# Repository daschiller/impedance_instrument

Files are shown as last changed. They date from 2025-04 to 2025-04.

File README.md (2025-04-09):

# Introduction

Source code and PCB design files for an impedance and temperature measurement
instrument. 

# Hardware

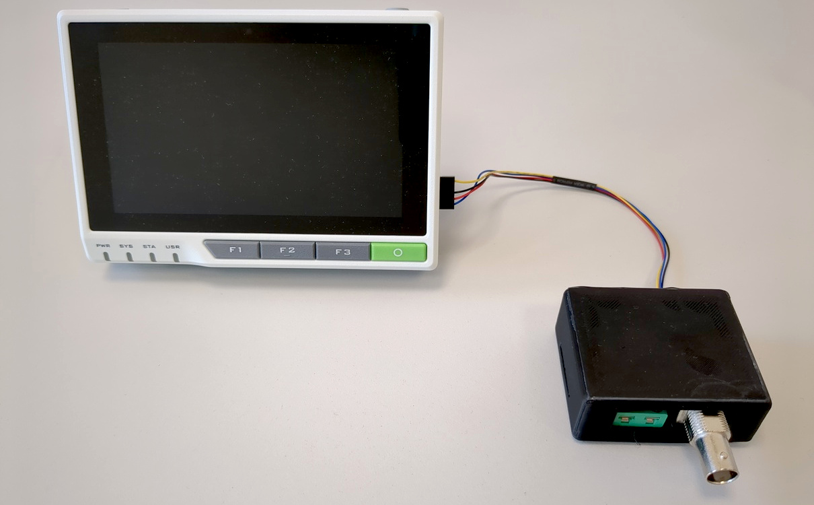
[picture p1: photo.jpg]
Photo of assembled device


The instrument features a BNC socket for connecting the device under test (DUT).
A standard miniature IEC socket allows the connection of a thermocouple.

The board has been designed in KiCad. You can use it to generate your own
Gerbers.

Here's a partial BOM:

* Impedance IC: AD5933
* Thermocouple IC: MCP9600
* Mux: ADG729

The control terminal is a [Seeed Studio
reTerminal](https://wiki.seeedstudio.com/reTerminal/) which is basically a
Raspberry Pi CM4 with a touchscreen and some other peripherals.

# Software

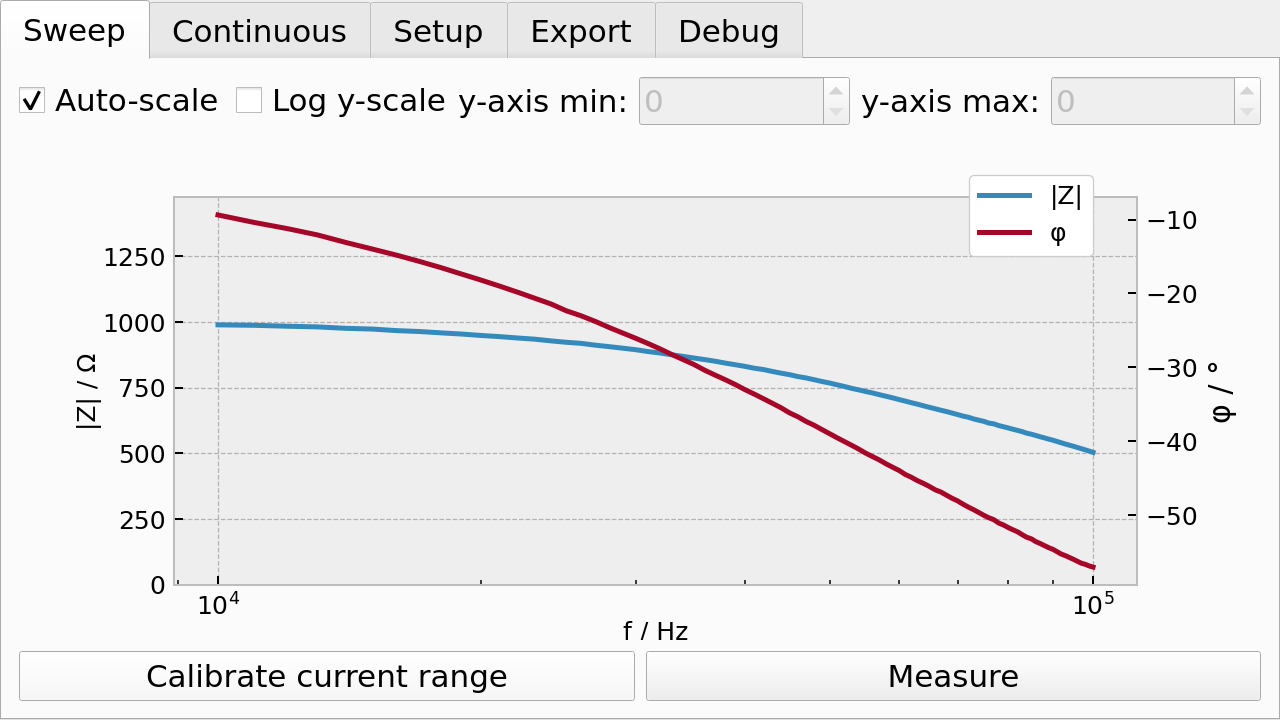
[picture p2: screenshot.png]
Screenshot of user interface


The software is built as a stage for
[pi-gen](https://github.com/RPi-Distro/pi-gen). Just drop it in and include it.
There's also a stage for the device tree and display driver of the reTerminal
device. Both of these are unfortunately not upstreamed.

After building, the result will be an image that can be directly written to the
device. It will boot straight into the UI. The Qt application runs on a DRM
framebuffer without a display server (EGLFS). The image has been tested with the
64 bit version of Bullseye.

The code does contain some out-of-tree modifications to the AD5933 IIO kernel
driver. It has been extended with variable clock rate support (for low
excitation frequencies). In the default implementation the clock is sourced from
the Raspberry Pi GPCLK peripheral.

Additionally, there's a tiny patch to libiio (included as a binary package in
this repo):
https://lore.kernel.org/all/1204b19a92343a9e3a6ec5df3cef94f6777e08c4.camel@jku.at/

# Manual

There's a manual that can be built with pandoc. Set up a LaTeX environment and
run the following to build a PDF:
```sh
make pdf
```
You can also generate a nice printable booklet using:
```sh
make booklet
```
This requires the `pdfbook2` script which is part of TeX Live and shipped in the
"texlive-extra-utils" package on Debian.

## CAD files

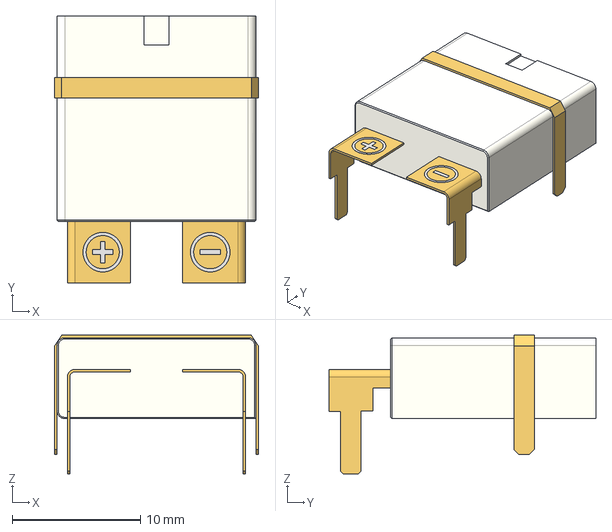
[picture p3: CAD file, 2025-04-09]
hardware/3d/SparkFun_-_PRT-13612.step
15.9 x 20.8 x 10.8 mm

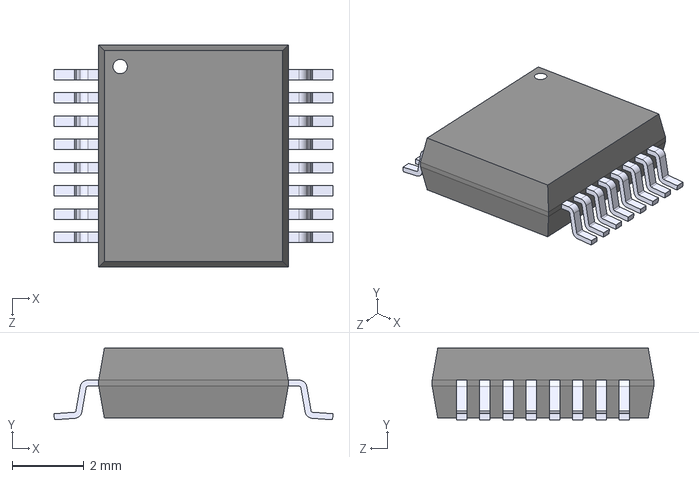
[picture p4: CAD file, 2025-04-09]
hardware/3d/AD5933YRSZ--3DModel-STEP-510211.STEP
7.80 x 2.00 x 6.20 mm

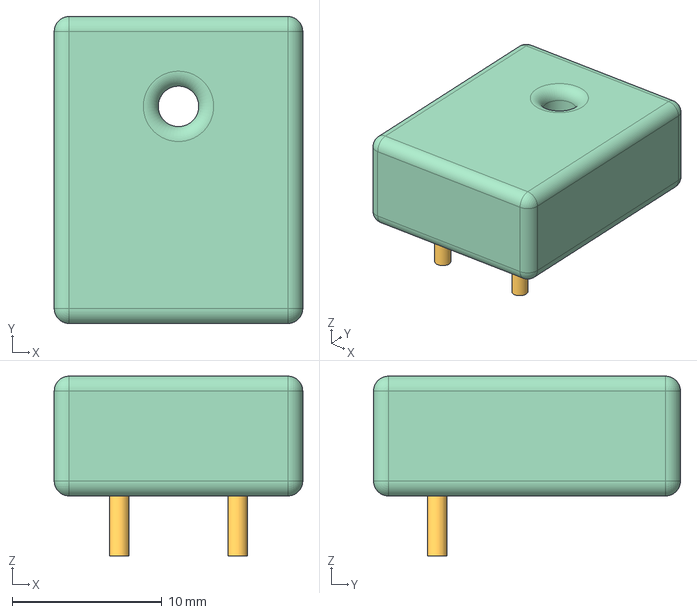
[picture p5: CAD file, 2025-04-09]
hardware/3d/thermocouple_block.step
16.6 x 20.5 x 12.0 mm

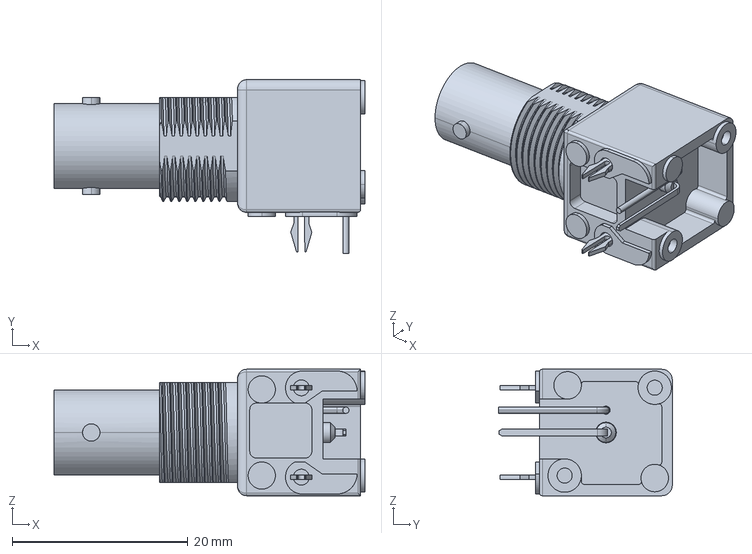
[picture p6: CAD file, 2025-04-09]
hardware/3d/31-5640-1010.stp
35.4 x 19.8 x 14.4 mm

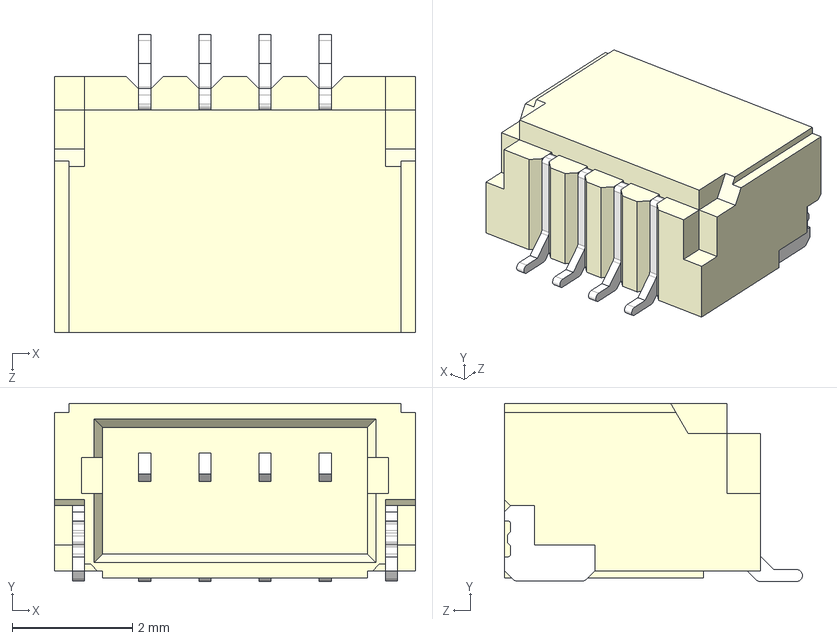
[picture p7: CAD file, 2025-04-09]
hardware/3d/SM04B-SRSS-TB(LF)(SN)--3DModel-STEP-269445.STEP
6.00 x 2.96 x 4.95 mm

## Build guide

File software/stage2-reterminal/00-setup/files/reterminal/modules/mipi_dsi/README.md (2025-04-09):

# mipi_dsi

### Features
This is a linux kernel driver for MIPI-DSI panel with touch panel attached to I2C bus.

### How to use
Add these lines to '/boot/config.txt':
```
dtparam=i2c_arm=on
dtparam=i2c_vc=on
ignore_lcd=1
dtoverlay=vc4-kms-v3d-pi4
dtoverlay=mipi_dsi-i2c10
```

Get the mipi_dsi source code, and install all linux kernel drivers:
```bash
git clone https://github.com/Seeed-Studio/seeed-linux-dtoverlays.git
git checkout mipi_dsi
make all_rpi
sudo make install_rpi
sudo reboot
```

You can get these file nodes from sysfs:
```
/sys/bus/mipi-dsi/devices/fe700000.dsi.0/
/dev/input/event0
```

Change Backlight:
```
# use root account
su root
# turn off
echo 0 > /sys/class/backlight/10-0045/brightness
# Half brightness
echo 125 > /sys/class/backlight/10-0045/brightness
# full brightness
echo 255 > /sys/class/backlight/10-0045/brightness
# exit root account
exit
```

Touchpanel Test:
```
$ evtest 
No device specified, trying to scan all of /dev/input/event*
Not running as root, no devices may be available.
Available devices:
/dev/input/event0:      seeed-tp
Select the device event number [0-0]: 0
Input driver version is 1.0.1
Input device ID: bus 0x18 vendor 0x1234 product 0x1001 version 0x100
Input device name: "seeed-tp"
Supported events:
  Event type 0 (EV_SYN)
  Event type 1 (EV_KEY)
    Event code 330 (BTN_TOUCH)
  Event type 3 (EV_ABS)
    Event code 0 (ABS_X)
      Value      0
      Min        0
      Max      480
    Event code 1 (ABS_Y)
      Value      0
      Min        0
      Max      854
    Event code 47 (ABS_MT_SLOT)
      Value      0
      Min        0
      Max        4
    Event code 53 (ABS_MT_POSITION_X)
      Value      0
      Min        0
      Max      480
    Event code 54 (ABS_MT_POSITION_Y)
      Value      0
      Min        0
      Max      854
    Event code 57 (ABS_MT_TRACKING_ID)
      Value      0
      Min        0
      Max    65535
Properties:
  Property type 1 (INPUT_PROP_DIRECT)
Testing ... (interrupt to exit)
Event: time 1608004517.527355, type 3 (EV_ABS), code 57 (ABS_MT_TRACKING_ID), value 0
Event: time 1608004517.527355, type 3 (EV_ABS), code 53 (ABS_MT_POSITION_X), value 223
Event: time 1608004517.527355, type 3 (EV_ABS), code 54 (ABS_MT_POSITION_Y), value 552
Event: time 1608004517.527355, type 1 (EV_KEY), code 330 (BTN_TOUCH), value 1
Event: time 1608004517.527355, type 3 (EV_ABS), code 0 (ABS_X), value 223
Event: time 1608004517.527355, type 3 (EV_ABS), code 1 (ABS_Y), value 552
Event: time 1608004517.527355, -------------- SYN_REPORT ------------
Event: time 1608004517.557357, type 3 (EV_ABS), code 54 (ABS_MT_POSITION_Y), value 551
Event: time 1608004517.557357, type 3 (EV_ABS), code 1 (ABS_Y), value 551
Event: time 1608004517.557357, -------------- SYN_REPORT ------------
Event: time 1608004517.685891, type 3 (EV_ABS), code 57 (ABS_MT_TRACKING_ID), value -1
Event: time 1608004517.685891, type 1 (EV_KEY), code 330 (BTN_TOUCH), value 0
Event: time 1608004517.685891, -------------- SYN_REPORT ------------
```

Enjoy !

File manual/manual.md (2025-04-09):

---
title: Impedance measurement device manual
subtitle: Version 1.1
author: David Schiller
lang: en-US
documentclass: scrartcl
classoption:
    - 10pt
papersize: a5
mainfont: STIX Two Text
mathfont: STIX Two Math
sansfont: Source Sans Pro
monofont: Source Code Pro
toc: true
colorlinks: false
urlstyle: tt
header-includes: |
    ```{=latex}
    \usepackage{siunitx}
    \KOMAoptions{headings=standardclasses,DIV=10}
    ```
---

\thispagestyle{empty}
\newpage
\KOMAoptions{twoside=true,DIV=calc,BCOR=12mm}

# Introduction

Photo of the device with control terminal and attached measurement board

The device is a combination of an industrial computer in the form of a
"Seeedstudio reTerminal" and a custom PCB with impedance and temperature
measurement capability. Unknown complex impedances (magnitude and phase) can be
characterized via frequency sweeps or continuous measurements at a fixed
frequency over time. The Analog Devices AD5933 IC is used for impedance
conversion and a Microchip MCP9600 serves as a thermocouple interface.

# Technical specifications

\enlargethispage*{\baselineskip}
* 5" $1280 \times 720$ capacitive touchscreen
* networking capability via Ethernet and Wi-Fi
* $\qty{32}{\giga\byte}$ of onboard storage
* two USB ports for external storage or other peripherals
* excitation frequency range: $\qtyrange{10}{100}{\kilo\hertz}$
* impedance measurement ranges by magnitude (based on estimates):
  - 1: $\qtyrange{15}{675}{\ohm}$
  - 2: $\qtyrange{1}{45}{\kilo\ohm}$
  - 3: $\qtyrange{100}{450}{\kilo\ohm}$
  - 4: $> \qty{1}{\mega\ohm}$
* thermocouple measurement accuracy: $\qty{+-1.5}{\celsius}$
* thermocouple measurement resolution: $\qty{0.0625}{\celsius}$

\pagebreak

# Basic operation

## Overview

You can turn on the device by pressing the button on the top left. A cold boot
should take around 15 seconds. You will be greeted with a touch-enabled user
interface grouped into five tabs:

1. *Sweep*: for frequency sweeps. The plot shows magnitude and phase over
   frequency.
2. *Continuous*: for continuous measurements. The plot shows magnitude over time
   at a fixed frequency.
3. *Setup*: provides a way to set parameters for both measurement modes. This
   includes
   * measurement range
   * start frequency
   * frequency increment
   * number of increments
4. *Export*: for saving acquired measurement data to disk
5. *Debug*: technical info helpful for troubleshooting

The front buttons labeled "F1", "F2" and "F3" allow quick switching between the
first three tabs. The green button is a shortcut for starting a measurement and
works both in sweep and continuous modes.

## Plot settings

These settings are largely the same between the two modes. You can select
between linear and logarithmic scaling for the vertical axis. By default, axis
scaling is performed automatically based on the measured data. You can override
this behavior by unchecking "Auto-scale" and setting the desired "y-min" and
"y-max" values. This comes into effect after the next measurement.

## Measurements

Before you can start a measurement, you have to perform a calibration step. The
terminals have to be left unconnected (floating) during this process. After
hitting "Calibrate current range", the currently selected range will be
calibrated using onboard calibration resistors. This process usually takes less
than ten seconds. From here on out, the calibration values reside in memory,
meaning re-calibration is necessary after power cycling the device. If you
desire the best accuracy, you should first wait for the device to warm up and
then periodically perform calibrations in between measurements. The latter is
especially important, if the ambient temperature is not stable.

### Sweep measurements

Screenshot of the "Sweep" tab --- the plot scale can be adjusted with the controls on top

Select the sweep parameters and the desired range in the "Setup" tab, before
hitting "Measure" or pushing the green button. The plot will show both magnitude
and phase over a logarithmically-scaled frequency axis. See "[Plot settings]"
for parameters affecting the y-axis.

### Continuous measurements

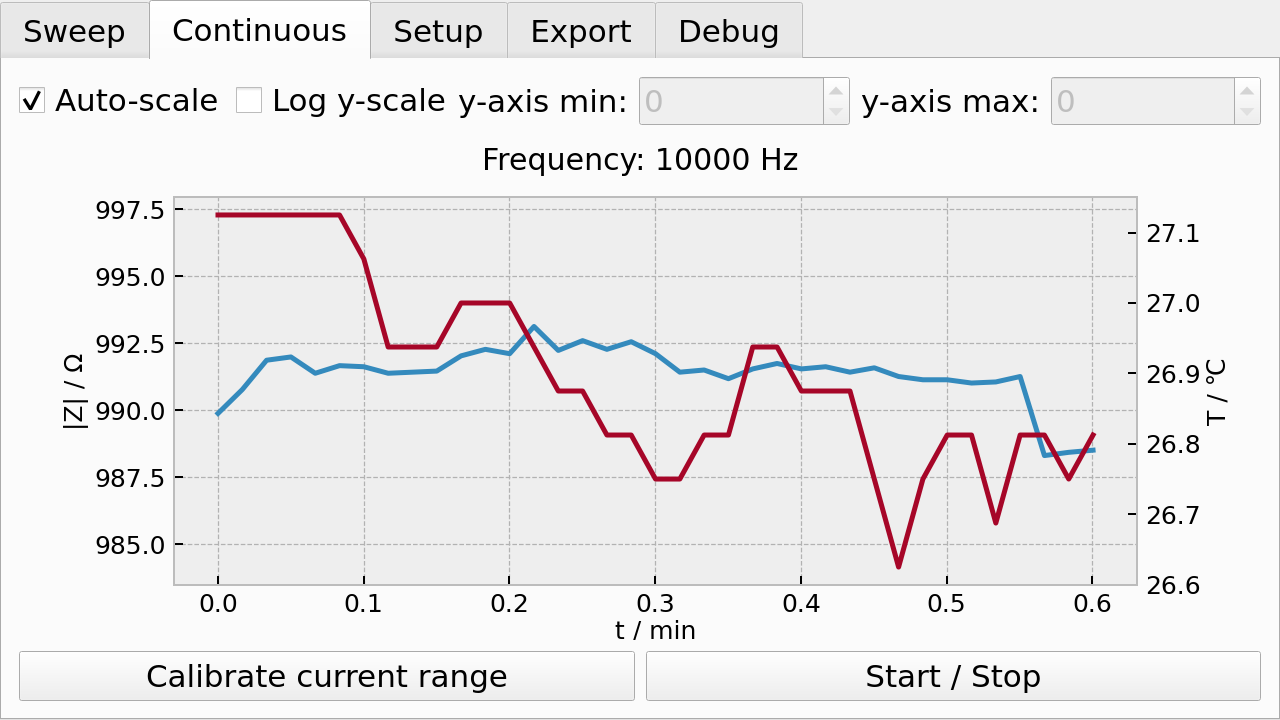
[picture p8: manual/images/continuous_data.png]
Screenshot of the "Continuous" tab --- the "Measure" button is replaced with a "Start / Stop" button


As before, you can set the measurement parameters in the "Setup" tab. The "Start
frequency" parameter from the sweep settings doubles as the fixed measurement
frequency in this mode. In contrast to the sweep mode, which is a one-shot
measurement, the continuous measurement has to be stopped explicitly --- either
via touch control or the physical button. The plot will also update as new data
is acquired. Because this is a potentially long-running process, the drawing and
measurement steps are offloaded to separate background threads. This means, that
you can navigate to a different tab, while the measurement continues to run.
This makes it possible to check the log for errors in the "Debug" tab, for
instance.

## Exporting data

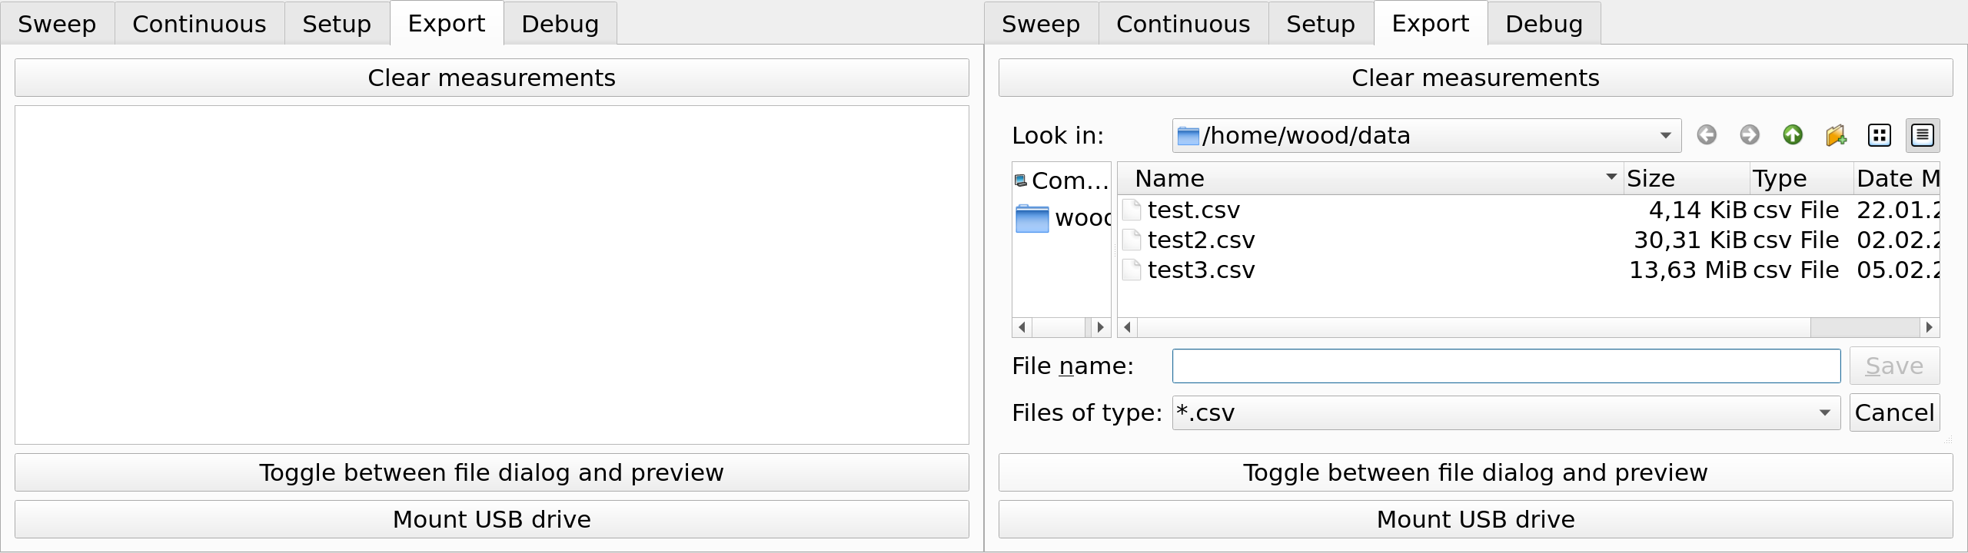
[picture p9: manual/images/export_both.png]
Screenshot of the "Export" tab --- a CSV preview of the current buffer is shown in the left image and the file picker is shown in the right image


The following is a general explanation of the data acquisition process. Repeated
measurements are saved to a temporary buffer located in memory. Individual
measurement series are tagged with an index that starts at zero and is
incremented by one for each series. The buffer is cleared in two situations:

* The user selects "Clear measurement" in the "Export tab".
* The user switches between one of the two measurement modes and initiates a new
  measurement --- only one type of data can reside in the buffer at the same
  time.

The "Export" tab features a preview of said buffer in CSV format and allows
writing the data to a file. The available columns shown in the preview depend on
the measurement mode. The above-mentioned index is represented as a separate
column and is always present.

At this point one can optionally mount an external drive with the "Mount USB
drive" button. The next step in the export process is to toggle to the file
dialog and select a target directory and file name. The starting directory in
this dialog is either a local directory or the root of an external drive,
depending on whether one was mounted in the previous step. Hit "Save" to write
the file and complete the process. Afterwards you can unmount the external
drive, if present, and/or clear the buffer.

# Advanced topics

## Measuring at low excitation frequencies

The AD5933 has an internal, fixed clock source running at $\qty{16}{\MHz}$. The
accuracy figures from the data sheet have been derived in this mode of
operation. Unfortunately, this has the side effect of severely limiting low
excitation frequency measurement performance, due to artifacts arising in the
DFT engine when clocked at this comparatively high rate. It is however possible
to connect an external clock signal to one of the AD5933's pins to mitigate this
issue. In the current revision of this device this is accomplished by dividing
down the crystal oscillator signal from the connected terminal and then feeding
it to the AD5933.

In effect this means that if you want to measure at frequencies lower than
around $\qty{3}{\kHz}$, you will have to lower the clock frequency from the
startup default of $\qty{9}{\MHz}$. The parameters in the following table
should ensure an accuracy of about $\pm \qty{5}{\percent}$.

| Clock frequency | Lower excitation frequency |
|---:|---:|
| 9 MHz | 3 kHz |
| 2.25 MHz | 1 kHz |
| 1.25 MHz | 500 Hz |
| 281250 Hz | 200 Hz |
| 140625 Hz | 100 Hz |
| 22500 Hz | 70 Hz |

: Clock frequencies and associated lower excitation frequency limits

It is not possible to generate clock frequencies below $\qty{22.5}{\kHz}$. For
the best possible phase accuracy you should stick to frequencies that can be
integer divided from $\qty{54}{\MHz}$ (Raspberry Pi crystal oscillator) without
remainder:

$$ f_\mathrm{clk} = \frac{f_\mathrm{osc}}{n} $$
$$ f_\mathrm{osc} \bmod n = 0 $$

This is because integer division yields the least amount of clock jitter. Keep
in mind that there is no one single clock frequency that can cover all frequency
ranges. For instance, at the lowest possible clock frequency, you have a useful
bandwidth of $\qtyrange{70}{1000}{\Hz}$. If you desire a wideband spectrum, you
have to split it into multiple sweeps with calibrations in between.

## Remote control via SSH

After you have established a network connection, you can connect to the device
via SSH. This enables you to transfer files from the internal storage or run the
GUI on your local machine using X11 forwarding. Assuming the device has
"10.0.0.2" as its IP address --- check the "Debug" tab for the currently
assigned address --- you can type the following to connect to it:

```sh
ssh -XC wood@10.0.0.2
```

The password is "knock". After establishing a connection, you can type:

```sh
start-gui -x
```

This will pop up a new window with the measurement GUI on your local machine.
The behavior is exactly identical to the touchscreen on the device itself, with
the added benefit of being able to resize the window, as well as having a
physical keyboard. Once you are done, just type "exit" at the prompt to close
the connection.

For file transfer you can use the "sftp" program or graphical file managers like
"FileZilla" or "WinSCP".

### Additional steps for Windows users

The process as described above assumes you have a working X server setup, which
is the case by default on Linux and is easily enabled on macOS. For Windows
users the quickest path is to set up "Windows Subsystem for Linux" (WSL) ---
notably version two.

On recent Windows versions (later versions of Windows 10, Windows 11) you can
open up a PowerShell prompt and then execute the following command:

```powershell
wsl --install
```

You will be prompted for a username and password along the way. If the command
finishes successfully, you should be able to find a "WSL" item in the start
menu. This will launch a shell in the WSL environment and from hereon out the
steps are identical to what is described above.

If you encounter any problems, please refer to the documentation provided by
Microsoft:

<https://learn.microsoft.com/en-us/windows/wsl/install>

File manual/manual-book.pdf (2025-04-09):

# Impedance measurement

# device manual

### Version 1.1

## David Schiller

## Contents

Introduction 3

Technical specifications 3

Basic operation 4

4 Overview |
4 Plot settings |
5 Measurements |
5 Sweep measurements |
5 Continuous measurements |
6 Exporting data |

Advanced topics 7

7 Measuring at low excitation frequencies |
8 Remote control via SSH |
9 Additional steps for Windows users |

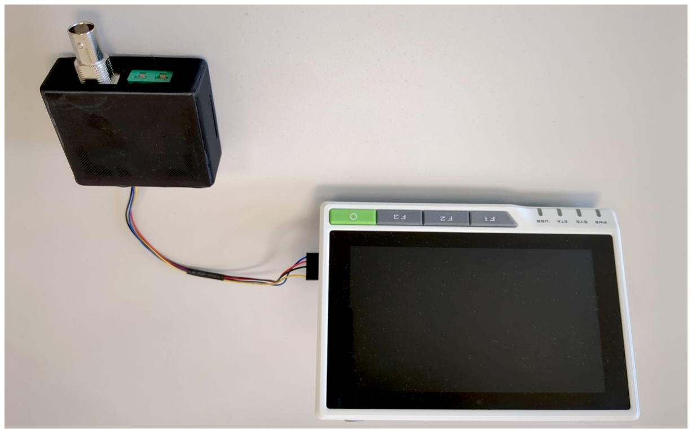
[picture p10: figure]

## Introduction

Photo of the device with control terminal and attached measure- Figure 1:

ment board

The device is a combination of an industrial computer in the form of a

“Seeedstudio reTerminal” and a custom PCB with impedance and temperature measurement capability. Unknown complex impedances (magnitude and phase) can be characterized via frequency sweeps or continuous measurements at a fixed frequency over time. The Analog Devices AD5933 IC is used for impedance conversion and a Microchip MCP9600 serves as a

thermocouple interface.

## Technical specifications

capacitive touchscreen 1280 × 720 5” • networking capability via Ethernet and Wi-Fi • of onboard storage GB 32 • two USB ports for external storage or other peripherals • kHz 100 to kHz 10 excitation frequency range: • impedance measurement ranges by magnitude (based on estimates): •

675 Ω to 15 Ω 1: –

Ωk 45 to Ωk1 2: –

Ωk 450 to Ωk 100 3: –

ΩM > 1 4: –

C ±1.5 ° thermocouple measurement accuracy: •

C 0.0625 ° thermocouple measurement resolution: •

## Basic operation

### Overview

You can turn on the device by pressing the button on the top left. A cold boot should take around 15 seconds. You will be greeted with a touch-enabled user interface grouped into five tabs:

1. Sweep: for frequency sweeps. The plot shows magnitude and phase over frequency.
2. Continuous: for continuous measurements. The plot shows magnitude over time at a fixed frequency.
3. Setup: provides a way to set parameters for both measurement modes. This includes
- measurement range
- start frequency
- frequency increment
- number of increments
4. Export: for saving acquired measurement data to disk
5. Debug: technical info helpful for troubleshooting

The front buttons labeled “F1”, “F2” and “F3” allow quick switching between the first three tabs. The green button is a shortcut for starting a measurement and works both in sweep and continuous modes.

### Plot settings

These settings are largely the same between the two modes. You can select between linear and logarithmic scaling for the vertical axis. By default, axis scaling is performed automatically based on the measured data. You can override this behavior by unchecking “Auto-scale” and setting the desired “y-min” and “y-max” values. This comes into effect after the next measurement.

This will pop up a new window with the measurement GUI on your local machine. The behavior is exactly identical to the touchscreen on the device itself, with the added benefit of being able to resize the window, as well as having a physical keyboard. Once you are done, just type “exit” at the prompt to close the connection.

For file transfer you can use the “sftp” program or graphical file managers like “FileZilla” or “WinSCP”.

Additional steps for Windows users

The process as described above assumes you have a working X server setup, which is the case by default on Linux and is easily enabled on macOS. For Windows users the quickest path is to set up “Windows Subsystem for Linux” (WSL) — notably version two.

On recent Windows versions (later versions of Windows 10, Windows 11) you can open up a PowerShell prompt and then execute the following command:

### wsl --install

You will be prompted for a username and password along the way. If the command finishes successfully, you should be able to find a “WSL” item in the start menu. This will launch a shell in the WSL environment and from hereon out the steps are identical to what is described above.

If you encounter any problems, please refer to the documentation provided by Microsoft:

### https://learn.microsoft.com/en-us/windows/wsl/insta

ll

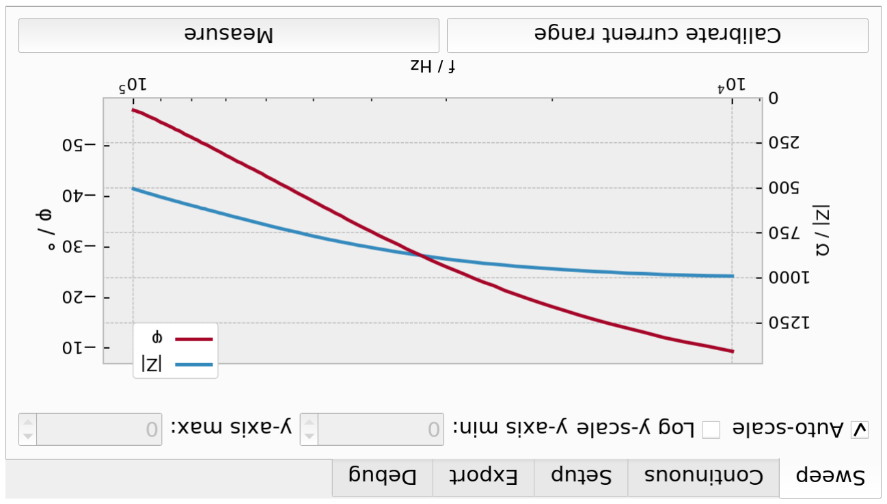
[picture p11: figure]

### Measurements

Before you can start a measurement, you have to perform a calibration step.

The terminals have to be left unconnected (floating) during this process.

After hitting “Calibrate current range”, the currently selected range will be calibrated using onboard calibration resistors. This process usually takes less than ten seconds. From here on out, the calibration values reside in memory, meaning re-calibration is necessary after power cycling the device.

If you desire the best accuracy, you should first wait for the device to warm up and then periodically perform calibrations in between measurements.

The latter is especially important, if the ambient temperature is not stable.

Sweep measurements

Screenshot of the “Sweep” tab — the plot scale can be adjusted Figure 2:

with the controls on top

Select the sweep parameters and the desired range in the “Setup” tab, before hitting “Measure” or pushing the green button. The plot will show both magnitude and phase over a logarithmically-scaled frequency axis. See

“Plot settings” for parameters affecting the y-axis.

Continuous measurements

As before, you can set the measurement parameters in the “Setup” tab.

The “Start frequency” parameter from the sweep settings doubles as the fixed measurement frequency in this mode. In contrast to the sweep mode,

Clock frequencies and associated lower excitation frequency limits Table 1:

Clock frequency Lower excitation frequency

9 MHz 3 kHz

2.25 MHz 1 kHz

1.25 MHz 500 Hz

281250 Hz 200 Hz

140625 Hz 100 Hz

22500 Hz 70 Hz

. For the best kHz 22.5 It is not possible to generate clock frequencies below possible phase accuracy you should stick to frequencies that can be integer

(Raspberry Pi crystal oscillator) without remainder: MHz 54 divided from

= clk f
osc f

n

n = 0 mod osc f

This is because integer division yields the least amount of clock jitter. Keep in mind that there is no one single clock frequency that can cover all frequency ranges. For instance, at the lowest possible clock frequency, you

. If you desire a wideband Hz 1000 to Hz 70 have a useful bandwidth of spectrum, you have to split it into multiple sweeps with calibrations in

between.

### Remote control via SSH

After you have established a network connection, you can connect to the device via SSH. This enables you to transfer files from the internal storage or run the GUI on your local machine using X11 forwarding. Assuming the device has “10.0.0.2” as its IP address — check the “Debug” tab for the currently assigned address — you can type the following to connect to it:

### wood@10.0.0.2 -XC ssh

The password is “knock”. After establishing a connection, you can type:

### -x start-gui


Figure 3: Screenshot of the “Continuous” tab — the “Measure” button is replaced with a “Start / Stop” button

which is a one-shot measurement, the continuous measurement has to be stopped explicitly — either via touch control or the physical button. The plot will also update as new data is acquired. Because this is a potentially long-running process, the drawing and measurement steps are offloaded to separate background threads. This means, that you can navigate to a different tab, while the measurement continues to run. This makes it possible to check the log for errors in the “Debug” tab, for instance.

### Exporting data


Figure 4: Screenshot of the “Export” tab — a CSV preview of the current buffer is shown in the left image and the file picker is shown in the right image

The following is a general explanation of the data acquisition process. Repeated measurements are saved to a temporary buffer located in memory.

Individual measurement series are tagged with an index that starts at zero and is incremented by one for each series. The buffer is cleared in two situations:

- The user selects “Clear measurement” in the “Export tab”.
- The user switches between one of the two measurement modes and initiates a new measurement — only one type of data can reside in the buffer at the same time.

The “Export” tab features a preview of said buffer in CSV format and allows writing the data to a file. The available columns shown in the preview depend on the measurement mode. The above-mentioned index is represented as a separate column and is always present.

At this point one can optionally mount an external drive with the “Mount USB drive” button. The next step in the export process is to toggle to the file dialog and select a target directory and file name. The starting directory in this dialog is either a local directory or the root of an external drive, depending on whether one was mounted in the previous step. Hit “Save” to write the file and complete the process. Afterwards you can unmount the external drive, if present, and/or clear the buffer.

## Advanced topics

### Measuring at low excitation frequencies

The AD5933 has an internal, fixed clock source running at 16 MHz. The accuracy figures from the data sheet have been derived in this mode of operation. Unfortunately, this has the side effect of severely limiting low excitation frequency measurement performance, due to artifacts arising in the DFT engine when clocked at this comparatively high rate. It is however possible to connect an external clock signal to one of the AD5933’s pins to mitigate this issue. In the current revision of this device this is accomplished by dividing down the crystal oscillator signal from the connected terminal and then feeding it to the AD5933.

In effect this means that if you want to measure at frequencies lower than around 3 kHz, you will have to lower the clock frequency from the startup default of 9 MHz. The parameters in the following table should ensure an accuracy of about ±5 %.

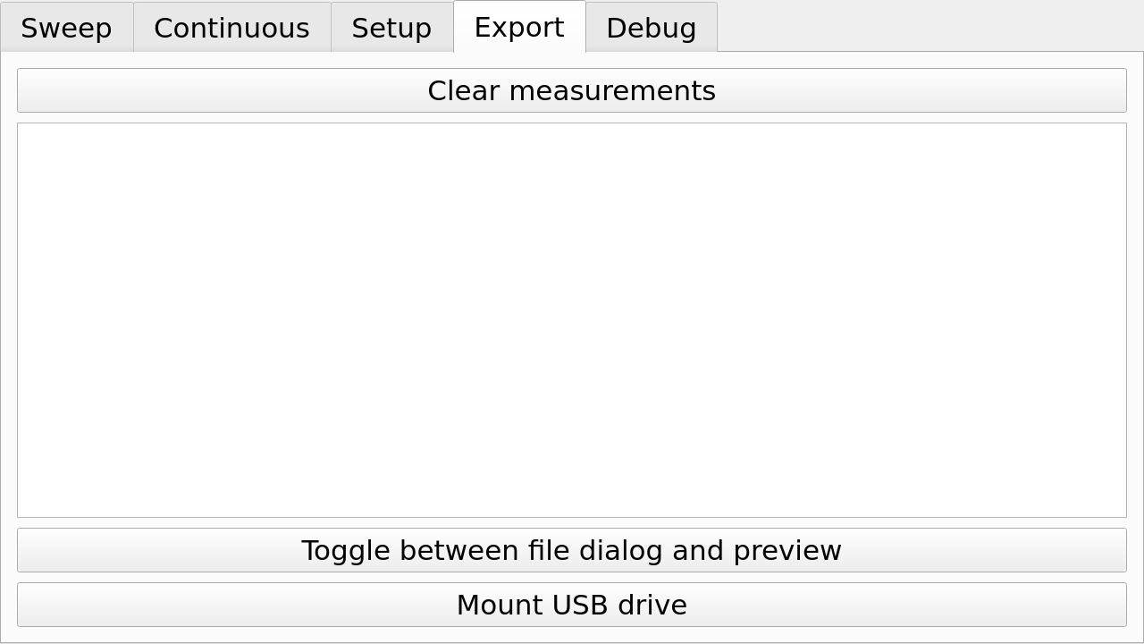
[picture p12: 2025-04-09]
manual/images/export_1.png

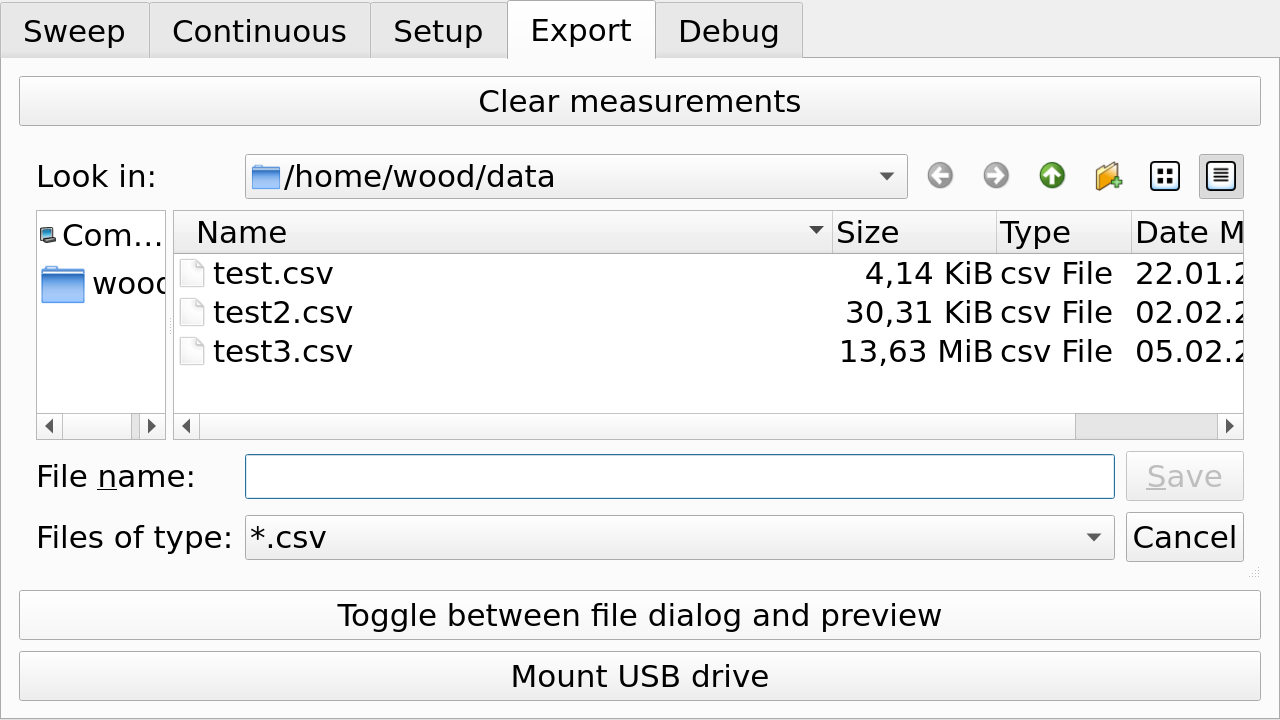
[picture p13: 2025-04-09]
manual/images/export_2.png

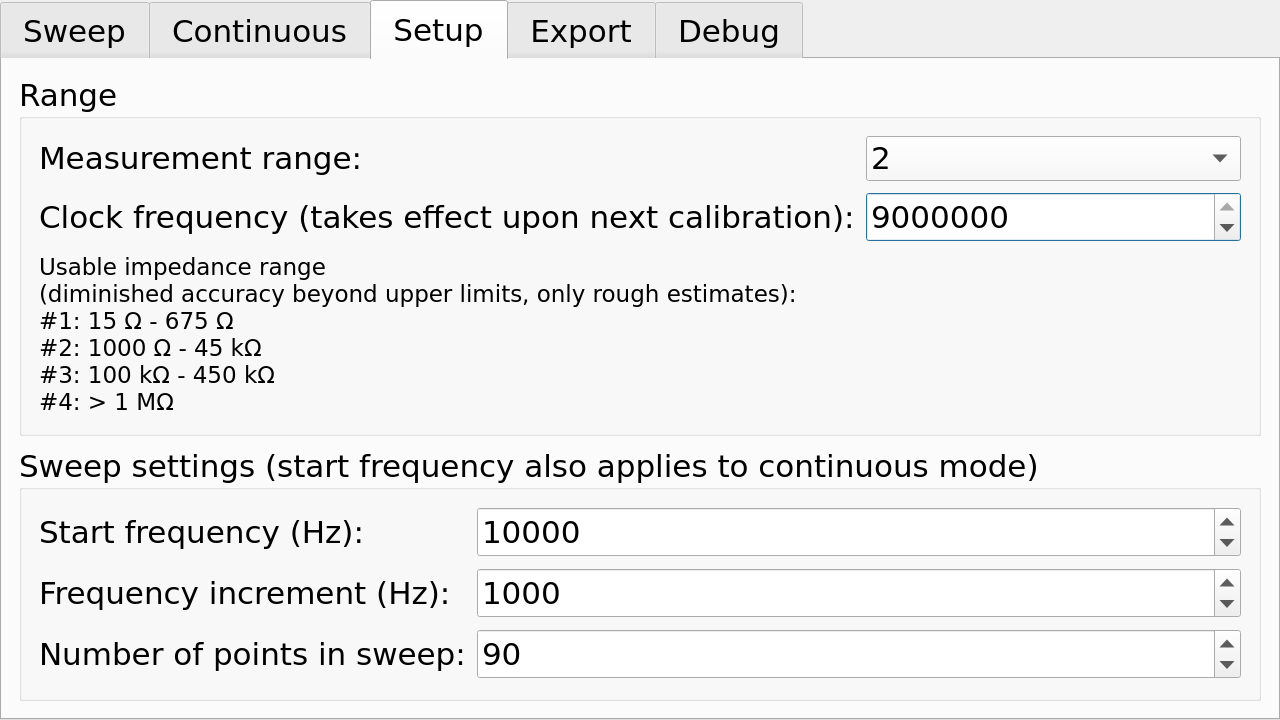
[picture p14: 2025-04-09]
manual/images/setup.png

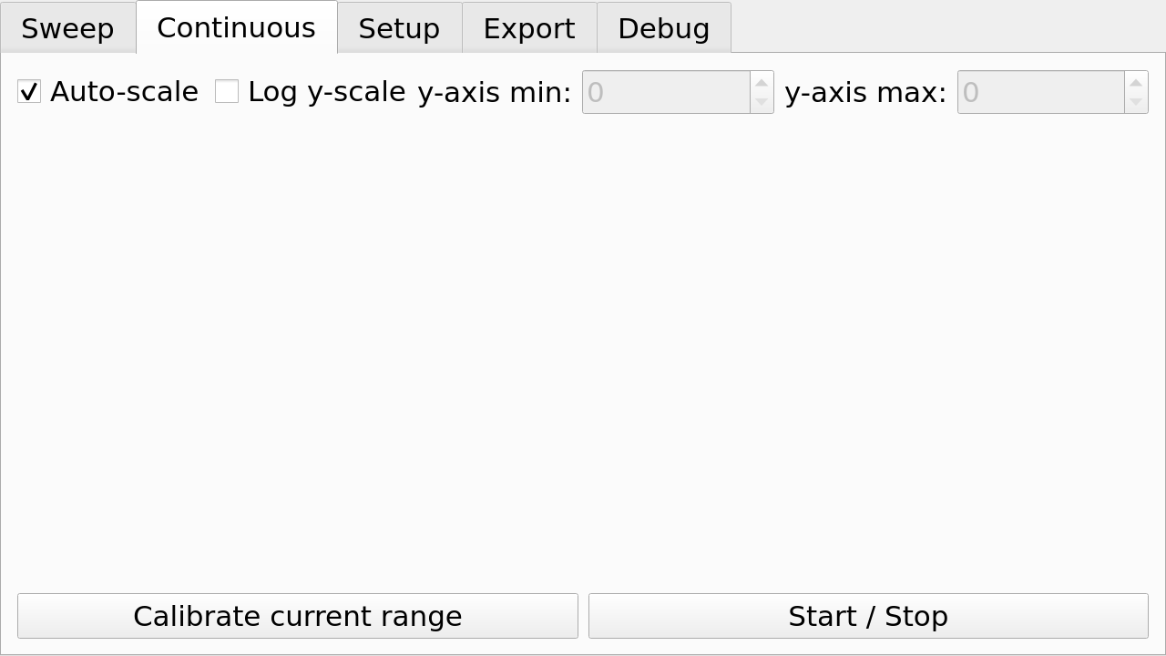
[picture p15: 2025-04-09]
manual/images/continuous.png

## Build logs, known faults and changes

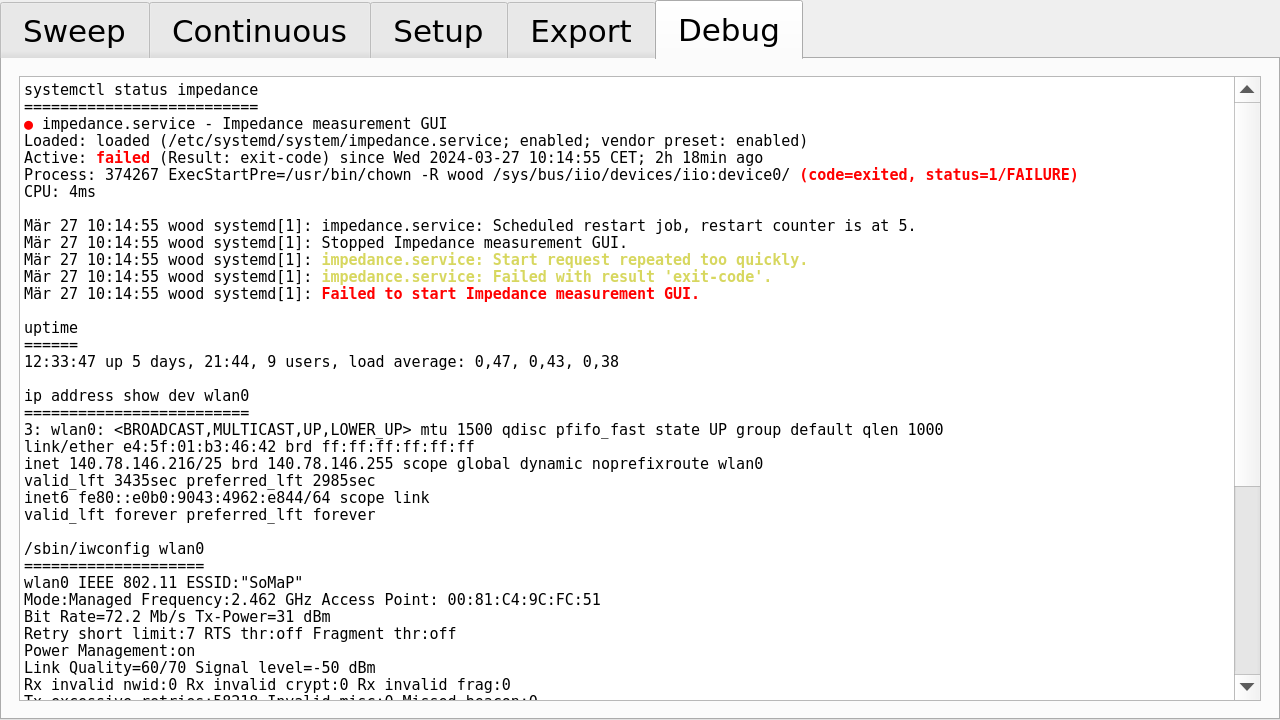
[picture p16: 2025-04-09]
manual/images/debug.png

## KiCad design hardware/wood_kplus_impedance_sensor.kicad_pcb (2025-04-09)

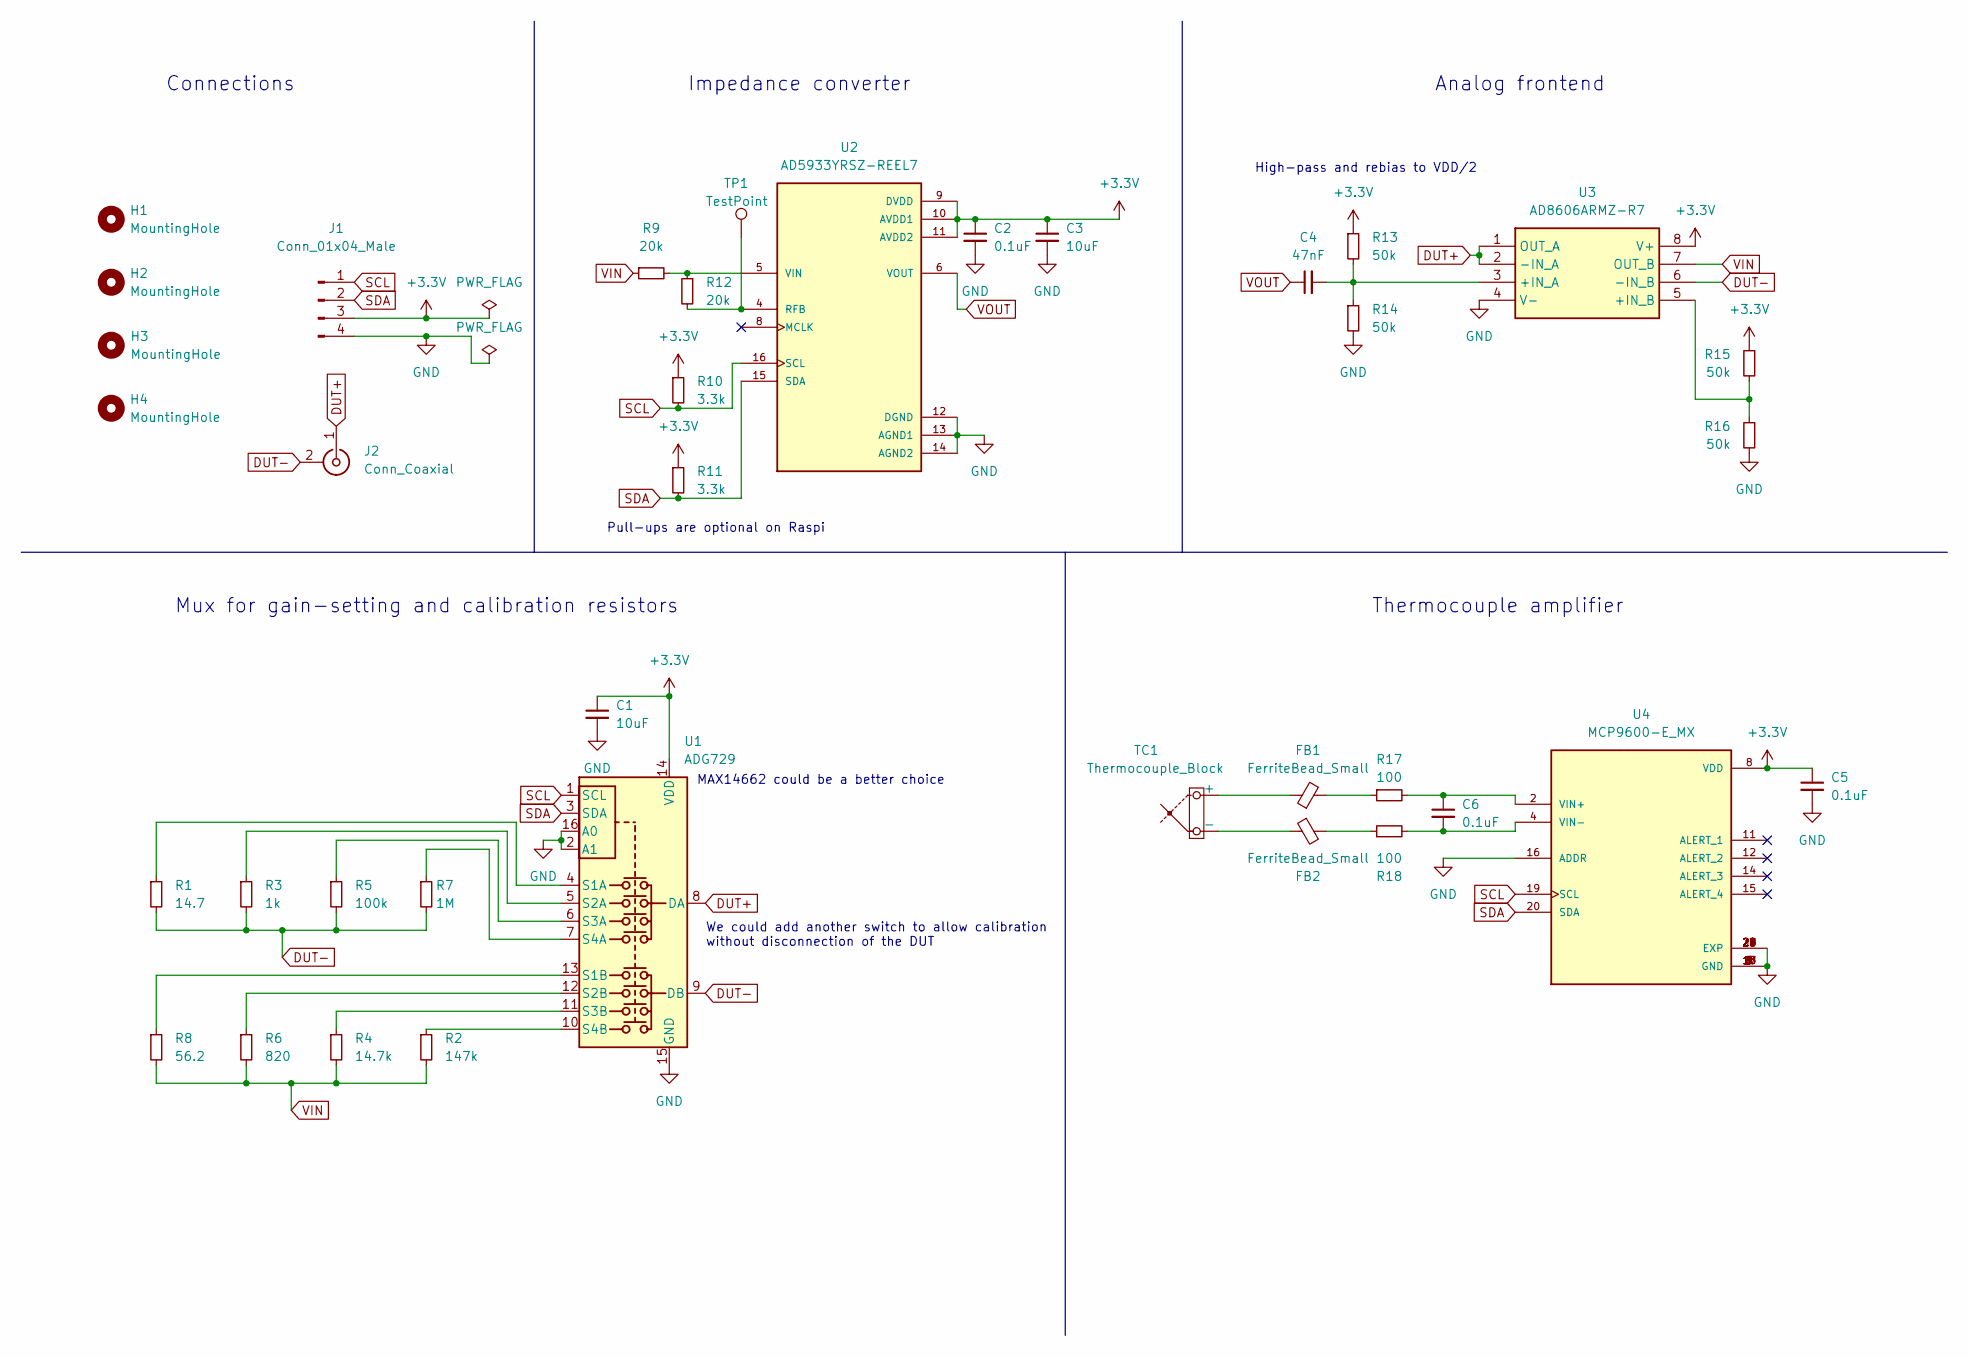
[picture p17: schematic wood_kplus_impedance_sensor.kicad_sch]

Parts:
C1, C3: 10uF; C_0603_1608Metric
C2, C5, C6: 0.1uF; C_0603_1608Metric
C4: 47nF; C_0603_1608Metric
FB1, FB2: FerriteBead_Small; L_0603_1608Metric; MPN C1002
H1, H2, H3, H4: MountingHole; MountingHole_3.2mm_M3
J1: Conn_01x04_Male; JST_SH_SM04B-SRSS-TB_1x04-1MP_P1.00mm_Horizontal
J2: Conn_Coaxial; BNC_Amphenol_B6252HB-NPP3G-50_Horizontal
R1: 14.7; R_0603_1608Metric
R2: 147k; R_0603_1608Metric
R3: 1k; R_0603_1608Metric
R4: 14.7k; R_0603_1608Metric
R5: 100k; R_0603_1608Metric
R6: 820; R_0603_1608Metric
R7: 1M; R_0603_1608Metric
R8: 56.2; R_0603_1608Metric
R9, R12: 20k; R_0603_1608Metric
R10, R11: 3.3k; R_0603_1608Metric
R13, R14, R15, R16: 50k; R_0603_1608Metric
R17, R18: 100; R_0603_1608Metric
TC1: Thermocouple_Block; RS_PRO_381-7564
TP1: TestPoint; TestPoint_Pad_D1.5mm
U1: ADG729; TSSOP-16_4.4x5mm_P0.65mm; JLCPCB Rotation Offset 90
U2: AD5933YRSZ-REEL7; SOP65P780X200-16N; PARTREV F; JLCPCB Rotation Offset -90
U3: AD8606ARMZ-R7; SOP65P490X110-8N; Manufacturer_Part_Number AD8606ARMZ-R7; Mouser Part Number 584-AD8606ARMZ-R7
U4: MCP9600-E_MX; QFN65P500X500X100-21N_MCP9600-E_MX; PARTREV F; JLCPCB Rotation Offset -90

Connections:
+3.3V: C1.1, C2.1, C3.1, C5.1, J1.3, R10.1, R11.1, R13.1, R15.1, U1.14 (VDD), U2.9 (DVDD), U2.10 (AVDD1), U2.11 (AVDD2), U3.8 (V+), U4.8 (VDD)
DUT+: J2.1 (In), U1.8 (DA), U3.1 (OUT_A), U3.2 (-IN_A)
DUT-: J2.2 (Ext), R1.2, R3.2, R5.2, R7.2, U1.9 (DB), U3.6 (-IN_B)
GND: C1.2, C2.2, C3.2, C5.2, J1.4, R14.2, R16.2, U1.2 (A1), U1.15 (GND), U1.16 (A0), U2.12 (DGND), U2.13 (AGND1), U2.14 (AGND2), U3.4 (V-), U4.1 (GND), U4.3 (GND), U4.5 (GND), U4.6 (GND), U4.7 (GND), U4.9 (GND), U4.10 (GND), U4.13 (GND), U4.16 (ADDR), U4.17 (GND), U4.18 (GND), U4.21 (EXP), U4.22 (EXP), U4.23 (EXP), U4.24 (EXP), U4.25 (EXP), U4.26 (EXP), U4.27 (EXP), U4.28 (EXP), U4.29 (EXP), U4.30 (EXP)
unnamed: FB1.2, R17.1
unnamed: FB2.2, R18.1
unnamed: FB1.1, TC1.1 (+)
unnamed: FB2.1, TC1.2 (-)
unnamed: R1.1, U1.4 (S1A)
unnamed: R8.1, U1.13 (S1B)
unnamed: R3.1, U1.5 (S2A)
unnamed: R6.1, U1.12 (S2B)
unnamed: R5.1, U1.6 (S3A)
unnamed: R4.1, U1.11 (S3B)
unnamed: R7.1, U1.7 (S4A)
unnamed: R2.1, U1.10 (S4B)
unnamed: R12.2, TP1.1, U2.4 (RFB)
unnamed: R9.2, R12.1, U2.5 (VIN)
unnamed: C4.2, R13.2, R14.1, U3.3 (+IN_A)
unnamed: R15.2, R16.1, U3.5 (+IN_B)
unnamed: C6.1, R17.2, U4.2 (VIN+)
unnamed: C6.2, R18.2, U4.4 (VIN-)
SCL: J1.1, R10.2, U1.1 (SCL), U2.16 (SCL), U4.19 (SCL)
SDA: J1.2, R11.2, U1.3 (SDA), U2.15 (SDA), U4.20 (SDA)
VIN: R2.2, R4.2, R6.2, R8.2, R9.1, U3.7 (OUT_B)
VOUT: C4.1, U2.6 (VOUT)

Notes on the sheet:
Mux for gain-setting and calibration resistors
MAX14662 could be a better choice
Pull-ups are optional on Raspi
Thermocouple amplifier
High-pass and rebias to VDD/2
We could add another switch to allow calibration without disconnection of the DUT
Analog frontend
Impedance converter
Connections

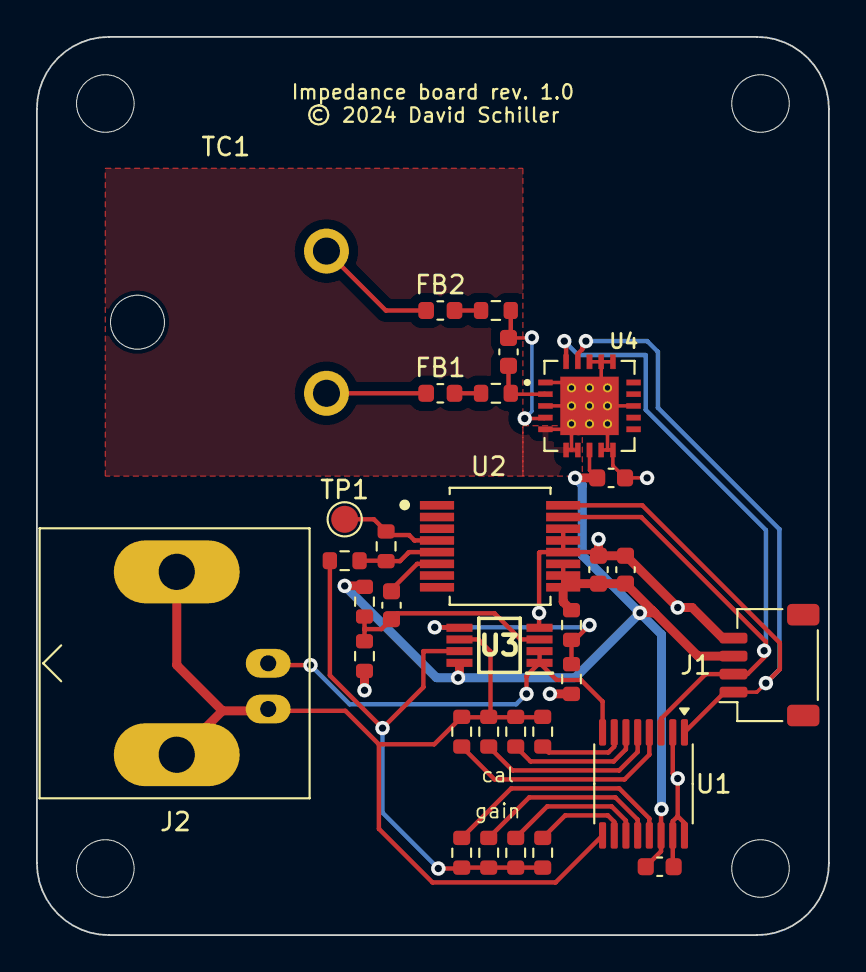
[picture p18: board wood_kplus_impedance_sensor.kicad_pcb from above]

Board: 2 copper layers, 44.0 x 49.9 mm, 36 parts (0 on the bottom side), 26 nets.

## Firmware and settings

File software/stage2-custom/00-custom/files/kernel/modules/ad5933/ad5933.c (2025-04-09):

// SPDX-License-Identifier: GPL-2.0
/*
 * AD5933 AD5934 Impedance Converter, Network Analyzer
 *
 * Copyright 2011 Analog Devices Inc.
 */

#include <linux/clk.h>
#include <linux/delay.h>
#include <linux/device.h>
#include <linux/err.h>
#include <linux/i2c.h>
#include <linux/interrupt.h>
#include <linux/kernel.h>
#include <linux/module.h>
#include <linux/regulator/consumer.h>
#include <linux/sysfs.h>
#include <linux/types.h>

#include <linux/iio/buffer.h>
#include <linux/iio/iio.h>
#include <linux/iio/kfifo_buf.h>
#include <linux/iio/sysfs.h>

/* AD5933/AD5934 Registers */
#define AD5933_REG_CONTROL_HB		0x80	/* R/W, 1 byte */
#define AD5933_REG_CONTROL_LB		0x81	/* R/W, 1 byte */
#define AD5933_REG_FREQ_START		0x82	/* R/W, 3 bytes */
#define AD5933_REG_FREQ_INC		0x85	/* R/W, 3 bytes */
#define AD5933_REG_INC_NUM		0x88	/* R/W, 2 bytes, 9 bit */
#define AD5933_REG_SETTLING_CYCLES	0x8A	/* R/W, 2 bytes */
#define AD5933_REG_STATUS		0x8F	/* R, 1 byte */
#define AD5933_REG_TEMP_DATA		0x92	/* R, 2 bytes*/
#define AD5933_REG_REAL_DATA		0x94	/* R, 2 bytes*/
#define AD5933_REG_IMAG_DATA		0x96	/* R, 2 bytes*/

/* AD5933_REG_CONTROL_HB Bits */
#define AD5933_CTRL_INIT_START_FREQ	(0x1 << 4)
#define AD5933_CTRL_START_SWEEP		(0x2 << 4)
#define AD5933_CTRL_INC_FREQ		(0x3 << 4)
#define AD5933_CTRL_REPEAT_FREQ		(0x4 << 4)
#define AD5933_CTRL_MEASURE_TEMP	(0x9 << 4)
#define AD5933_CTRL_POWER_DOWN		(0xA << 4)
#define AD5933_CTRL_STANDBY		(0xB << 4)

#define AD5933_CTRL_RANGE_2000mVpp	(0x0 << 1)
#define AD5933_CTRL_RANGE_200mVpp	(0x1 << 1)
#define AD5933_CTRL_RANGE_400mVpp	(0x2 << 1)
#define AD5933_CTRL_RANGE_1000mVpp	(0x3 << 1)
#define AD5933_CTRL_RANGE(x)		((x) << 1)

#define AD5933_CTRL_PGA_GAIN_1		(0x1 << 0)
#define AD5933_CTRL_PGA_GAIN_5		(0x0 << 0)

/* AD5933_REG_CONTROL_LB Bits */
#define AD5933_CTRL_RESET		(0x1 << 4)
#define AD5933_CTRL_INT_SYSCLK		(0x0 << 3)
#define AD5933_CTRL_EXT_SYSCLK		(0x1 << 3)

/* AD5933_REG_STATUS Bits */
#define AD5933_STAT_TEMP_VALID		(0x1 << 0)
#define AD5933_STAT_DATA_VALID		(0x1 << 1)
#define AD5933_STAT_SWEEP_DONE		(0x1 << 2)

/* I2C Block Commands */
#define AD5933_I2C_BLOCK_WRITE		0xA0
#define AD5933_I2C_BLOCK_READ		0xA1
#define AD5933_I2C_ADDR_POINTER		0xB0

/* Device Specs */
#define AD5933_INT_OSC_FREQ_Hz		16776000
#define AD5933_EXT_OSC_FREQ_Hz		9000000
#define AD5933_MAX_OUTPUT_FREQ_Hz	100000
#define AD5933_MAX_RETRIES		100

#define AD5933_OUT_RANGE		1
#define AD5933_OUT_RANGE_AVAIL		2
#define AD5933_OUT_SETTLING_CYCLES	3
#define AD5933_IN_PGA_GAIN		4
#define AD5933_IN_PGA_GAIN_AVAIL	5
#define AD5933_FREQ_POINTS		6

#define AD5933_POLL_TIME_ms		10
#define AD5933_INIT_EXCITATION_TIME_ms	100

struct ad5933_state {
	struct i2c_client		*client;
	struct regulator		*reg;
	struct clk			*mclk;
	struct delayed_work		work;
	struct mutex			lock; /* Protect sensor state */
	unsigned long			mclk_hz;
	unsigned char			ctrl_hb;
	unsigned char			ctrl_lb;
	unsigned int			range_avail[4];
	unsigned short			vref_mv;
	unsigned short			settling_cycles;
	unsigned short			freq_points;
	unsigned int			freq_start;
	unsigned int			freq_inc;
	unsigned int			state;
	unsigned int			poll_time_jiffies;
};

#define AD5933_CHANNEL(_type, _extend_name, _info_mask_separate, _address, \
		_scan_index, _realbits) { \
	.type = (_type), \
	.extend_name = (_extend_name), \
	.info_mask_separate = (_info_mask_separate), \
	.address = (_address), \
	.scan_index = (_scan_index), \
	.scan_type = { \
		.sign = 's', \
		.realbits = (_realbits), \
		.storagebits = 16, \
	}, \
}

static const struct iio_chan_spec ad5933_channels[] = {
	AD5933_CHANNEL(IIO_TEMP, NULL, BIT(IIO_CHAN_INFO_RAW) |
		BIT(IIO_CHAN_INFO_SCALE), AD5933_REG_TEMP_DATA, -1, 14),
	/* Ring Channels */
	AD5933_CHANNEL(IIO_VOLTAGE, "real", 0, AD5933_REG_REAL_DATA, 0, 16),
	AD5933_CHANNEL(IIO_VOLTAGE, "imag", 0, AD5933_REG_IMAG_DATA, 1, 16),
};

static int ad5933_i2c_write(struct i2c_client *client, u8 reg, u8 len, u8 *data)
{
	int ret;

	while (len--) {
		ret = i2c_smbus_write_byte_data(client, reg++, *data++);
		if (ret < 0) {
			dev_err(&client->dev, "I2C write error\n");
			return ret;
		}
	}
	return 0;
}

static int ad5933_i2c_read(struct i2c_client *client, u8 reg, u8 len, u8 *data)
{
	int ret;

	while (len--) {
		ret = i2c_smbus_read_byte_data(client, reg++);
		if (ret < 0) {
			dev_err(&client->dev, "I2C read error\n");
			return ret;
		}
		*data++ = ret;
	}
	return 0;
}

static int ad5933_cmd(struct ad5933_state *st, unsigned char cmd)
{
	unsigned char dat = st->ctrl_hb | cmd;

	return ad5933_i2c_write(st->client,
			AD5933_REG_CONTROL_HB, 1, &dat);
}

static int ad5933_reset(struct ad5933_state *st)
{
	unsigned char dat = st->ctrl_lb | AD5933_CTRL_RESET;

	return ad5933_i2c_write(st->client,
			AD5933_REG_CONTROL_LB, 1, &dat);
}

static int ad5933_wait_busy(struct ad5933_state *st, unsigned char event)
{
	unsigned char val, timeout = AD5933_MAX_RETRIES;
	int ret;

	while (timeout--) {
		ret =  ad5933_i2c_read(st->client, AD5933_REG_STATUS, 1, &val);
		if (ret < 0)
			return ret;
		if (val & event)
			return val;
		cpu_relax();
		mdelay(1);
	}

	return -EAGAIN;
}

static int ad5933_set_freq(struct ad5933_state *st,
			   unsigned int reg, unsigned long freq)
{
	unsigned long long freqreg;
	union {
		__be32 d32;
		u8 d8[4];
	} dat;

	freqreg = (u64)freq * (u64)(1 << 27);
	do_div(freqreg, st->mclk_hz / 4);

	switch (reg) {
	case AD5933_REG_FREQ_START:
		st->freq_start = freq;
		break;
	case AD5933_REG_FREQ_INC:
		st->freq_inc = freq;
		break;
	default:
		return -EINVAL;
	}

	dat.d32 = cpu_to_be32(freqreg);
	return ad5933_i2c_write(st->client, reg, 3, &dat.d8[1]);
}

static int ad5933_change_clock(struct ad5933_state *st, unsigned long clock) {
	/*
	 * We have to toggle the ENAB bit in the control register to ensure
	 * that the current divider settings actually apply.
	 * This is an ugly workaround!
	 */
#define CM_GP0CTL 0xfe101070
	void __iomem *reg = ioremap(CM_GP0CTL, 4);
	u32 val;

	// printk(KERN_DEBUG "ad5933: clock = %lu\n", clock);
	val = readl(reg);
	writel(0x5a000000 | (val & ~(1 << 4)), reg);
	while(readl(reg) & (1 << 7)) {
		;
	}
	clk_set_rate(st->mclk, clock);
	st->mclk_hz = clk_get_rate(st->mclk);
	val = readl(reg);
	writel(0x5a000000 | val | (1 << 4), reg);
    iounmap(reg);

	return 0;
}


static int ad5933_setup(struct ad5933_state *st)
{
	__be16 dat;
	int ret;

	ret = ad5933_reset(st);
	if (ret < 0)
		return ret;

	ret = ad5933_set_freq(st, AD5933_REG_FREQ_START, 10000);
	if (ret < 0)
		return ret;

	ret = ad5933_set_freq(st, AD5933_REG_FREQ_INC, 200);
	if (ret < 0)
		return ret;

	st->settling_cycles = 10;
	dat = cpu_to_be16(st->settling_cycles);

	ret = ad5933_i2c_write(st->client,
			       AD5933_REG_SETTLING_CYCLES,
			       2, (u8 *)&dat);
	if (ret < 0)
		return ret;

	st->freq_points = 100;
	dat = cpu_to_be16(st->freq_points);

	return ad5933_i2c_write(st->client, AD5933_REG_INC_NUM, 2, (u8 *)&dat);
}
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

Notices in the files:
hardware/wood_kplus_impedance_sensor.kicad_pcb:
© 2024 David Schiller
